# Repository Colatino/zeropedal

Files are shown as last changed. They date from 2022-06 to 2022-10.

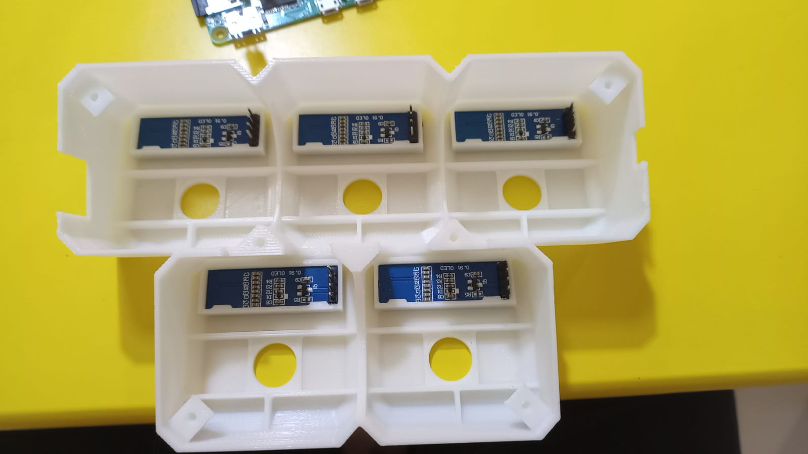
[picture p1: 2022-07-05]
pictures/assembly/WhatsApp Image 2022-07-04 at 21.12.29 (1).jpeg

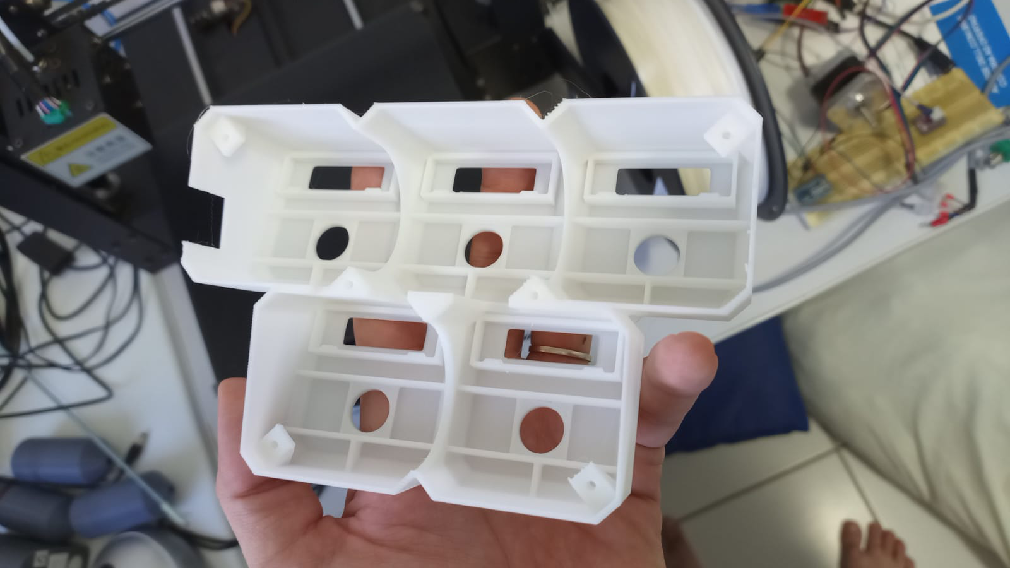
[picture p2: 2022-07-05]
pictures/assembly/WhatsApp Image 2022-07-04 at 21.12.29.jpeg

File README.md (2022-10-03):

# ZEROPEDAL (Deprecated)
Raspberry Pi Zero midi pedal controller for Zoom pedals. 


The purpose of this project is to build an auxiliary pedal controller to be used with Zoom multi-effects processors like the G1XFour (tested with this model) and toggle individual effects on/off.

This is a software and hardware project.

The code is written in Python (tested on 3.7 and 3.9) and is largely based and inspired on [zoom-zt2](https://github.com/mungewell/zoom-zt2) and [ZoomPedalFun](https://github.com/shooking/ZoomPedalFun)

# DEMO VIDEOS (no sound)
Demo video 1 (https://www.youtube.com/watch?v=D9xH5quKueQ)
Demo video 2 (https://www.youtube.com/watch?v=8XPy8AvLA0o)

## BILL OF MATERIALS
- 1 x Raspberry Pi Zero (mine is a zero w with a busted wifi chip)
- 1 x SD card 8GB or more
- 5 x SSD1306 0.91" oled displays
- 1 x TC9548A
- 5 x SPST momentary footswitches
- 1 x female USB type A breakout board
- 1 x female micro USB breakout board
- 10 x 2.2kOhm resistor 
- Some jumper wires
- Some box or case to contain everything - mine is 3d printed and the files are available on the case folder

The RPi zero is the most expensive part, everything costs around US$ 1 or less on aliexpress

## DEPENDENCIES
This project makes use of the following:
- A deprecated [Adafruit Python SSD1306 library](https://github.com/adafruit/Adafruit_Python_SSD1306) and its dependencies
- [MIDO](https://mido.readthedocs.io/en/latest/) and its dependencies
- [VCR OSD MONO font](https://www.dafont.com/vcr-osd-mono.font)  by [Riciery Leal](https://www.dafont.com/mrmanet.d5509)

### TODO list
- [x] Design and print case
- [x] Detect when pedal is unplugged

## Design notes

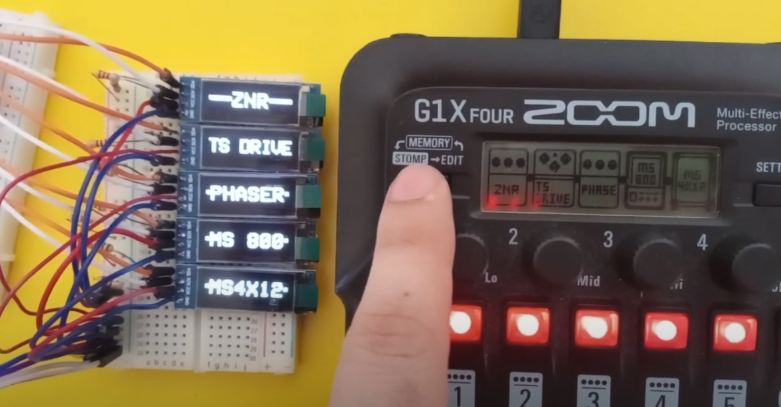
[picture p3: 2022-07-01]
pictures/video_snapshot.jpg

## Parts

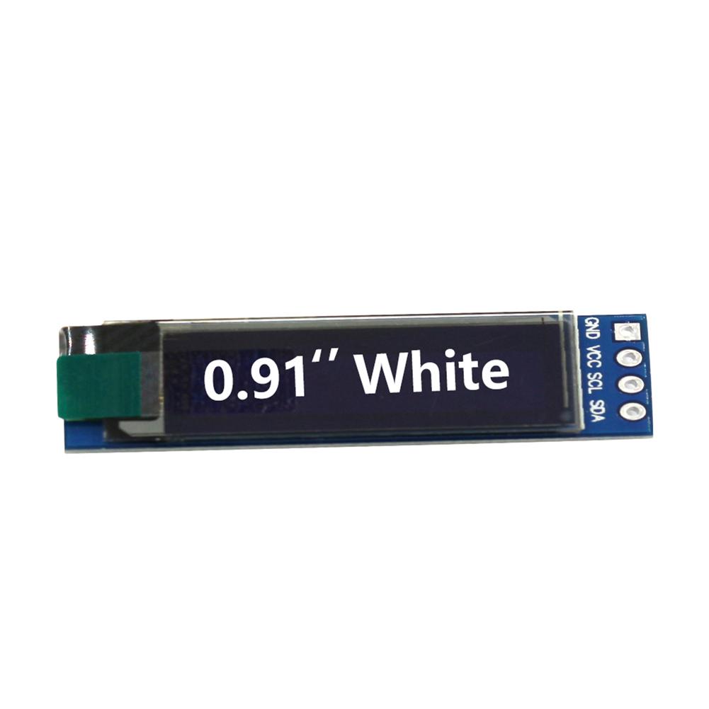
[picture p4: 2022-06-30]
pictures/parts/oledscreen.jpg

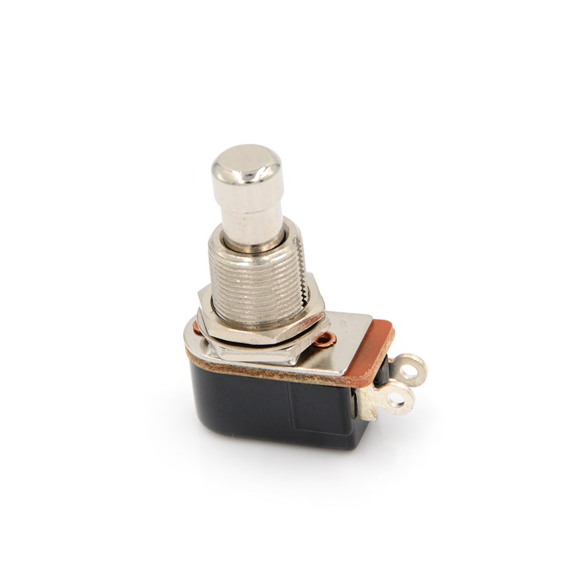
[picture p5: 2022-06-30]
pictures/parts/footswitch.jpg

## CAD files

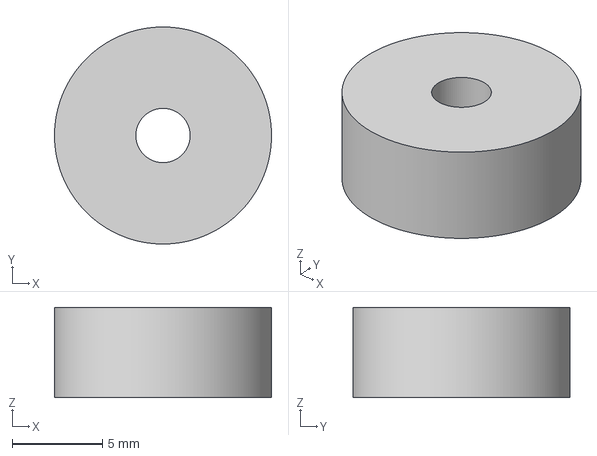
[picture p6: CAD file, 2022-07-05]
case/foot_v0.3mf
12.0 x 12.0 x 5.00 mm

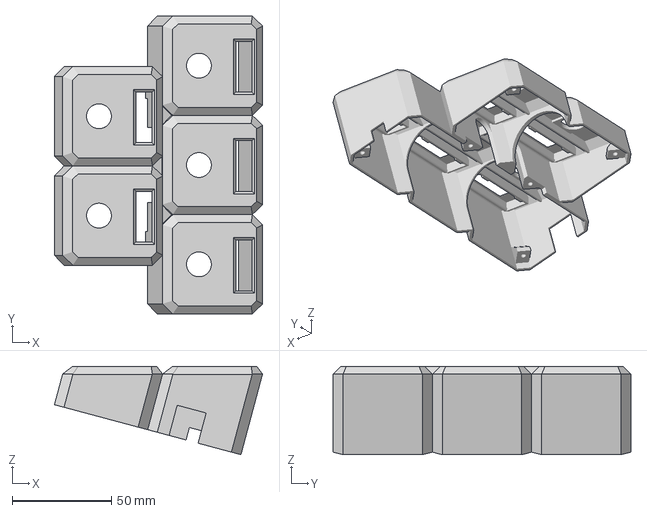
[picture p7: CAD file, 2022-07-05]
case/case_v2.3mf
104.8 x 150.0 x 44.5 mm

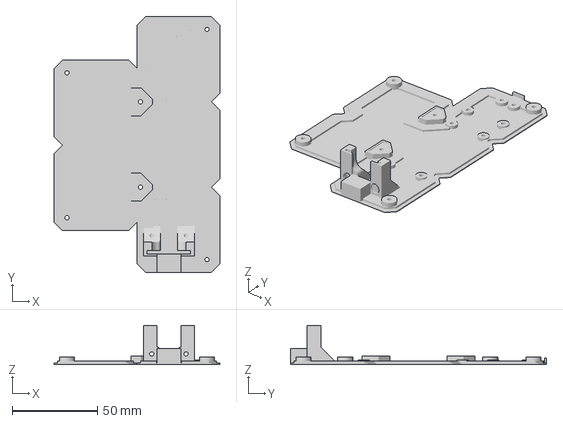
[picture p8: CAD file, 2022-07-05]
case/base_v0.3mf
97.2 x 150.0 x 23.0 mm

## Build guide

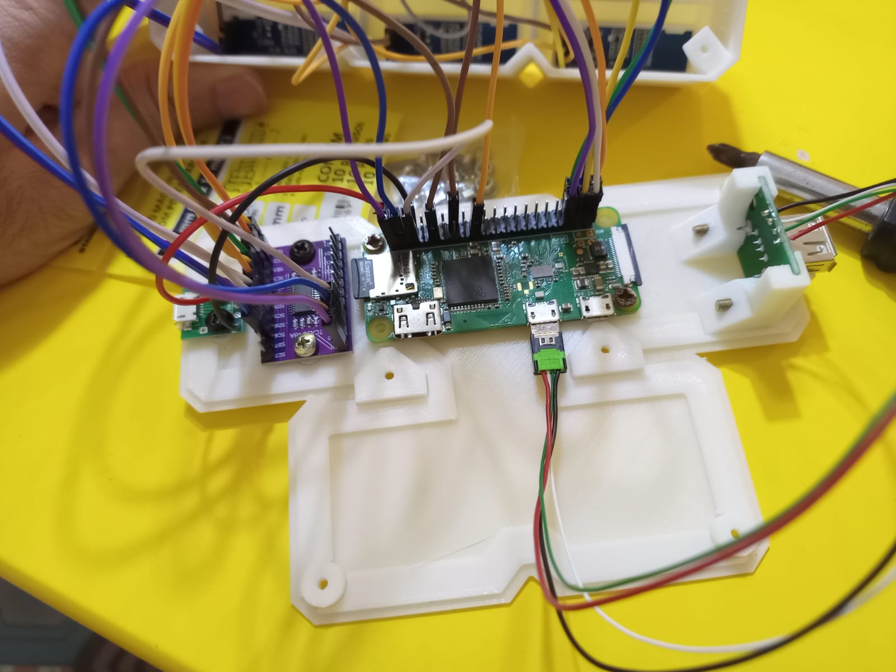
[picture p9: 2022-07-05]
pictures/assembly/WhatsApp Image 2022-07-04 at 21.12.30 (1).jpeg

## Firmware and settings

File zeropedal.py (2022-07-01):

import time
import math
import sys
import queue

# Initialize the FIFO task queue
q=queue.Queue()

linux=False
if sys.platform =='linux':
    linux=True
    import Adafruit_SSD1306
    from Adafruit_GPIO import I2C
    import RPi.GPIO as PINS

from PIL import Image
from PIL import ImageDraw
from PIL import ImageFont

from minizt2 import zoomzt2

# Helper footswitch class
class Footswitch:
    def __init__(self,pin,id):
        # pin the footswitch is attached to
        self.pin=pin
        # id of the footswitch, must be the same as its display
        self.id=id
        # set the pin and activate its internal pullup resistor
        PINS.setup(pin,PINS.IN,pull_up_down=PINS.PUD_UP)
        
    # Called when switch is pressed (interrupt routine)
    # MUST be as short as possible
    def callback(self,pin):
        if not PINS.input(pin):
            # Add a task to the queue to be resolved on the main loop
            q.put(self.id)

class Controller:
    fontname="./font/VCR_OSD_MONO_1.001.ttf"
    init_done=False
    need_redraw=False
    def __init__(self,pins=[],oleds=[],address=0x70,width=128,height=32):
        #Footpedal switch pins
        self.switch_pins=pins
        
        self.switches=[]
        
        self.pedal=zoomzt2()
        
        if linux:        
            #Oled screens multiplexer buses
            self.oled_bus=oleds
            
            #TCA9548A I2C multiplexer
            self.tca=I2C.get_i2c_device(address)            

            # 128 x 32 OLED display with I2C
            self.width=width
            self.height=height
            self.disp=Adafruit_SSD1306.SSD1306_128_32(rst=None)

            # Init Drawing object
            self.image=Image.new('1',(width,height))
            self.draw=ImageDraw.Draw(self.image)
            self.draw.rectangle((0,0,width,height), outline=0, fill=0)
            # Draw the bypass line
            self.draw.rectangle((0,height/2-4,width,height/2+4),outline=0,fill=1,width=2)
            
            for b in oleds:
                #Select display bus
                self.tca.writeRaw8(1<<b)

                # Initialize display library
                self.disp.begin()

                # Clear display
                self.disp.clear()
                self.disp.image(self.image)
                self.disp.display()
                self.display_select_none()

            text="Waiting"
            self.font = ImageFont.truetype(self.fontname,28)  
            lx,ly=self.font.getsize(text)
            pos_x = ( self.width - lx ) / 2
            pos_y = ( self.height - ly ) / 2

            PINS.setmode(PINS.BCM)
            for i,p in enumerate(pins):
                self.switches.append(Footswitch(p,i))    
    
    # Select display idx bus on the multiplexer
    def display_select(self,idx):
        self.tca.writeRaw8(1<<idx)
    
    # Deselect all displays
    def display_select_none(self):
        self.tca.writeRaw8(0)
        
    # Draw a text, can be multiline up to 4 lines
    def draw_text(self,idx,text):
        try:
            if idx < len(self.oled_bus) and linux:
                self.display_select(idx)
                self.draw.rectangle((0,0,self.width,self.height), outline=0, fill=0)
                
                fontsize=self.height
                # Reload font
                self.font = ImageFont.truetype(self.fontname,fontsize)
                while True:
                    #Try the largest font possible (32 px)
                    lx,ly=self.font.getsize(text)
                    if fontsize>=16 and lx <= self.width:
                        pos_x = ( self.width - lx ) / 2
                        pos_y = ( self.height - ly ) / 2
                        
                        # Effect name
                        self.draw.text((pos_x,pos_y),text,font=self.font,fill=255)
                        break
                    elif fontsize < 16:
                        nlines = math.ceil(lx/self.width)
                        maxlines = int(32/ly)
                        if nlines < maxlines:
                            lines= math.ceil(lx / self.width)
                            cursor=0
                            for l in range(lines):
                                end=len(text)
                                pos_y = ( l * ly )
                                lsize,_=self.font.getsize(text[cursor:end])
                                while lsize > self.width:
                                    end-=1
                                    lsize,_=self.font.getsize(text[cursor:end])
                                self.draw.text((0,pos_y),text[cursor:end],font=self.font,fill=255)
                                pos_y+=ly
                                cursor=end
                                end=len(text)
                            break
                            
                    
                    #Reduce font size by 1 and check for text size
                    fontsize-=1
                    self.font = ImageFont.truetype(self.fontname,fontsize)
                    if fontsize < 8:
                        done=True
                # Display image.
                self.disp.image(self.image)
                self.disp.display()
                self.display_select_none()
            else:
                print(text)
        except:
            pass
     
    # Main drawing method. Shows the effect name and bypass line behind (effect on) or in front (effect off)
    def redraw(self,switch):
        try:
            if linux and switch < len(self.oled_bus):
                # Draw a black filled box to clear the image
                self.draw.rectangle((0,0,self.width,self.height), outline=0, fill=0)
                # Draw the bypass line
                self.draw.rectangle((0,self.height/2-4,self.width,self.height/2+4),outline=0,fill=1,width=2)
                # Get effect name linked to the pressed switch
                text=self.pedal.patch.get_name(index=switch)
                
                if not text=="BYPASS":
                    fontsize=self.height
                    # Load font
                    self.font = ImageFont.truetype(self.fontname,fontsize)                
                    #Try the largest font possible (32 px)
                    lx,ly=self.font.getsize(text)
                    while lx > self.width or ly > self.height:
                        #Reduce font size by 1 and check for text size
                        fontsize-=1
                        self.font = ImageFont.truetype(self.fontname,fontsize)
                        lx,ly = self.font.getsize(text)
                    pos_x = ( self.width - lx ) / 2
                    pos_y = ( self.height - ly ) / 2
                    
                    # Black container
                    self.draw.rectangle((pos_x,pos_y,pos_x+lx,pos_y+ly),outline=0,fill=0)
                    # Effect name
                    self.draw.text((pos_x,pos_y),text,font=self.font,fill=255)
                    # Draw bypass line after the name if disabled
                    if not self.pedal.patch.states[switch]:
                        self.draw.rectangle((0,self.height/2-4,self.width,self.height/2+4),outline=0,fill=1,width=2)   
                # Display image
                self.display_select(self.oled_bus[switch])
                self.disp.clear()
                self.disp.image(self.image)
                self.disp.display()
                self.display_select_none()
                return True
            else:
                text=self.pedal.patch.get_name(index=switch)
                print (text)
                return False
                
        except:
            return False
    
    # Refresh pedal model with current patch information
    # useful when editing the patch on the pedal while connected
    def refresh_model(self):
        for n in range(self.pedal.patch._n_effects):
            self.redraw(n)
            
if __name__=='__main__':
    
    # Pins connected to the foot switches
    switch_pins=[19,16,26,20,21]
    
    # Buses on the multiplexer used to control the oled displays
    oled_bus=[6,5,4,3,2]

    # Initialization info
    controller=Controller(switch_pins,oled_bus)
    loaded=time.perf_counter()
    controller.draw_text(0,"zeropedal v 0.1")
    time.sleep(.5)
    controller.draw_text(0,"Init took "+str(round(loaded,2))+" s")
    time.sleep(.5)
    controller.draw_text(0,"Waiting")
    
    # Wait for device to connect
    while not controller.pedal.connected:
        if controller.pedal.connect():
            break
    print("connected")            
    controller.draw_text(0,"Connected")
    controller.pedal.editor_on()
    controller.draw_text(1,"Loading patch...")
    controller.pedal.patch_download_current()            
    controller.draw_text(0,controller.pedal.patch.name)
    controller.draw_text(1,"Loaded!")
    time.sleep(0.5)
    controller.refresh_model()

    controller.init_done=True
    
    # Attach an interrupt routine to each footswitch
    for s in controller.switches:
        # Detects falling edge
        detect=PINS.FALLING #other possible values PINS.RISING or PINS.BOTH
        # Debounce time
        debounce=100
        # Attach routine
        PINS.add_event_detect(s.pin,detect,callback=s.callback,bouncetime=debounce)
    
    # Main loop
    while True:
        try:
            # Resolve queued tasks
            while not q.empty():
                index=None
                # Pop a task (if any) from the q  
                index=q.get_nowait()
                if not index==None:
                    # Toggle selected effect
                    controller.pedal.toggle_effect(index=index)
                    # Redraw effect state
                    controller.redraw(index)
            # Check pedal for incoming messages
            res,data=controller.pedal.task()
            if res:
                # Got a patch/bank change message
                controller.refresh_model()
            else:
                # Got a patch updated (effects changed) message
                if not data==None:
                    slot=data[0]
                    index=controller.pedal.patch.get_index(slot=slot)
                    controller.pedal.patch.states[index]=data[1]
                    controller.redraw(index)
        except Exception as e:
            print(str(e))

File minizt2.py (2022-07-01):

import mido
from g1xfour import effects
import time

class Effects:
    effects={}
    
    def __init__(self):
        for e in effects:
            tempeffect={}
            tempeffect={"name":e[0],
                        "id":e[1],
                        "group":e[2]
                        "filename":e[3],
                        "nslots":e[4],
                        "nparam":e[5],
                        "params":[]}
            for p in e[6]:
                tempparam={}
                tempparam={"pedal":p[0],
                           "maxval":p[1],
                           "defval":p[2],
                           "curval":p[3],
                           "name":p[4]}
                tempeffect["params"].append(tempparam)
                
            self.effects[e[1]]=tempeffect

    def find(self,id):
        return self.effects[id]
    
    def get_size(self,id):
        return self.find(id)['nslots']
    
    def get_name(self,id):
        return self.find(id)['name'].upper()
    
class Patch:
    _cur_slot=0
    _n_effects=0
    name=""
    names=[]
    ids=[]
    slots=[]
    states=[]
        
    def add_effect(self,id,state,effects):
        self.ids.append(id)
        self.states.append(state)
        self.names.append(effects.get_name(id))        
        self.slots.append(self._cur_slot)
        self._cur_slot+=effects.get_size(id)
        self._n_effects+=1
        
    def get_index(self,slot=None,id=None):
        if not slot==None:
            return self.slots.index(slot)
        
        if not id==None:
            return self.ids.index(id)
    
    def get_slot(self,index=None,id=None):
        if not index==None:
            return self.slots[index]
        
        if not id==None:
            return self.slots[self.ids,index(id)]

    def get_name(self,slot=None,id=None,index=None):
        if not slot==None:
            return self.names[self.slots.index(slot)]
        
        if not id==None:
            return self.names[self.ids.index(id)]
        
        if not index==None:
            return self.names[index]
                 
    def clear(self):
        self.names=[]
        self.ids=[]
        self.slots=[]
        self.states=[]
        self._cur_slot=0
        self._n_effects=0
    
    def get_state(self,slot=None,index=None,id=None):
        if not slot==None:
            return self.states[self.slots.index(slot)]
        
        if not index==None:
            return self.states[index]
        
        if not id==None:
            return self.states[self.ids.index(slot)]

    def set_state(self,state,slot=None,index=None,id=None):
        if not slot==None:
            self.states[self.slots.index(slot)]=state
        
        if not index==None:
            self.states[index]=state

        if not id==None:
            self.states[self.ids.index(id)]=state

class zoomzt2(object):
    midiname="ZOOM G"
    inport = None
    outport = None
    editor = False
    connected = False
    
    effects=Effects()
    patch=Patch()

    def is_connected(self):
        if self.inport == None or self.outport == None or not self.connected:
            return False
        else:
            return True

    def connect(self):
        try:
            for port in mido.get_input_names():
                if port[:len(self.midiname)]==self.midiname:
                    self.inport = mido.open_input(port)
                    self.outport = mido.open_output(port)
                    break

            if self.inport == None or self.outport == None:
                return False
            self.connected = True
            return True
        except Exception as e:
            print(str(e))
            return False

    def disconnect(self):
        if self.editor:
            self.editor_off()
        
        self.inport.close()
        self.inport = None
        self.outport.close()
        self.outport = None
        self.connected = False

    def editor_on(self):
        # Enable Editor Mode
        msg = mido.Message("sysex", data = [0x52, 0x00, 0x6e, 0x50])
        self.outport.send(msg); msg = self.inport.receive()
        self.editor = True

    def editor_off(self):
        # Disable Editor Mode
        msg = mido.Message("sysex", data = [0x52, 0x00, 0x6e, 0x51])
        self.outport.send(msg); msg = self.inport.receive()
        self.editor = False
    
    def toggle_effect(self,slot=None,index=None):

        if not index==None:
            if index > len(self.patch.slots):return [False,None]
            slot=self.patch.get_slot(index=index)

        if not slot==None:
            if not slot in self.patch.slots:return [False,None]
            index=self.patch.get_index(slot=slot)
      
        if not self.patch.ids[index] == 0:
            state=self.patch.get_state(index=index)
            if not state:
                msg=mido.Message('sysex',data=[0x52 ,0x00 ,0x6E ,0x64 ,0x03 ,0x00 ,slot ,0x00 ,0x00 ,0x02 ,0x00 ,0x00 ,0x00])
            else:
                msg=mido.Message('sysex',data=[0x52 ,0x00 ,0x6E ,0x64 ,0x03 ,0x00 ,slot ,0x00 ,0x00 ,0x00 ,0x00 ,0x00 ,0x00])
            self.outport.send(msg); msg = self.inport.receive()
            state=not state
            self.patch.set_state(state,index=index)
            return [True,state]

    def unpack(self, packet):
        # Unpack data 7bit to 8bit, MSBs in first byte
        data = bytearray(b"")
        loop = -1
        hibits = 0

        for byte in packet:
            if loop !=-1:
                if (hibits & (2**loop)):
                    data.append(128 + byte)
                else:
                    data.append(byte)
                loop = loop - 1
            else:
                hibits = byte
                loop = 6
        return(data)
    
    def parse_patch(self,data):
        try:
            self.patch.clear()
            self.patch.name=data[26:36].rstrip().decode("utf-8")

            edtb=data.split(b'EDTB')[1].split(b'PPRM')[0]
            neff=int(edtb[0]/24)
            
            for i in range(neff):    
                bits=''        
                union=edtb[7+i*24]<<24 | edtb[6+i*24]<<16 | edtb[5+i*24]<<8 | edtb[4+i*24]
                id=(union>>1) & 0xfffffff
                self.patch.add_effect(id,union & 1,self.effects)
            return True
        except:
            return False
              
    def patch_download_current(self):
        try:
            msg = mido.Message("sysex", data = [0x52, 0x00, 0x6e, 0x29])
        
            self.clear_buffer()
            
            self.outport.send(msg); msg = self.inport.receive()
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

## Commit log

2022-06-24 Interrupt with switchs
2022-06-26 Wait for device and load patch
2022-06-29 Major version fix #1, fix closes #2
    [minizt2.py, zeropedal.py]
2022-07-05 major update
    [base_v0.3mf, case_v2.3mf, foot_v0.3mf]
